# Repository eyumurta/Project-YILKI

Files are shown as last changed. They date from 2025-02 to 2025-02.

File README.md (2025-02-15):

This is the first Prototype of Open Plc Controller Board Yılkı.This project devoloped with Eagle
Project started 2024.
First Protype doesn't have built in Power,mcu circuits. This PT1 is only creating for testing input,output and Rs485 line.
I'm not a hardware engineer so project maybe have faulty designs.This Board using Stm32f0 Discovery board to handle inputs and outputs.
You can see inputs state by LED.But power calculations are wrong so I'm not soldered the Leds and their resistors.In theory boards outputs can drive relay but not tested. 

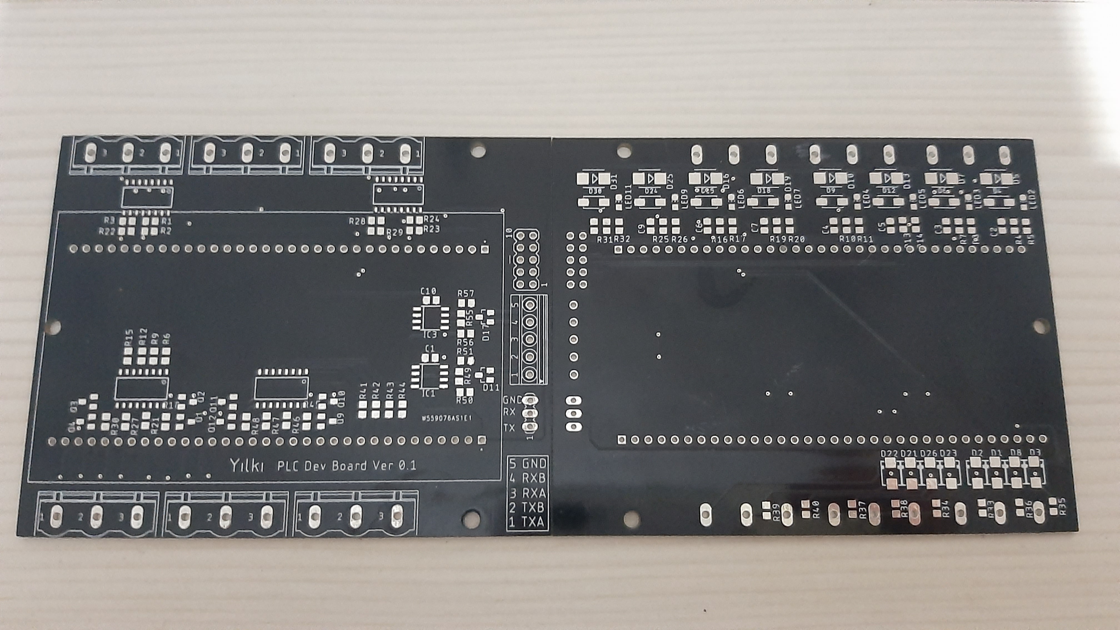
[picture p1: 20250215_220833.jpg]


Input Side:
Inputs Are Designed sink (0v Common).Protected by TVS diode and optocoupler.Added RC filter for ripples.

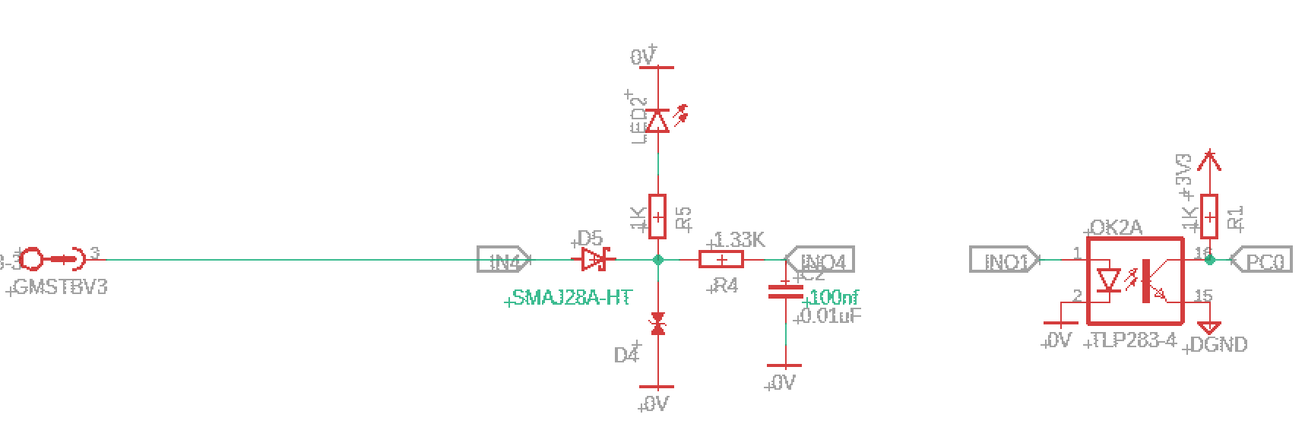
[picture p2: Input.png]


Output Side:
Outputs are Designed source(24V Common).Outputs Protected by Optocoupler and reverse diode for relay.

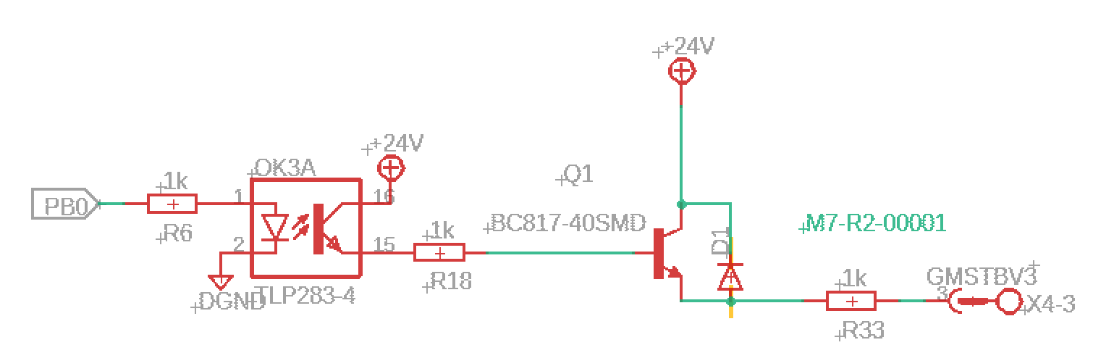
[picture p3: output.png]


Full Duplex RS-485:
This circuit is Full Duplex Rs-485 line

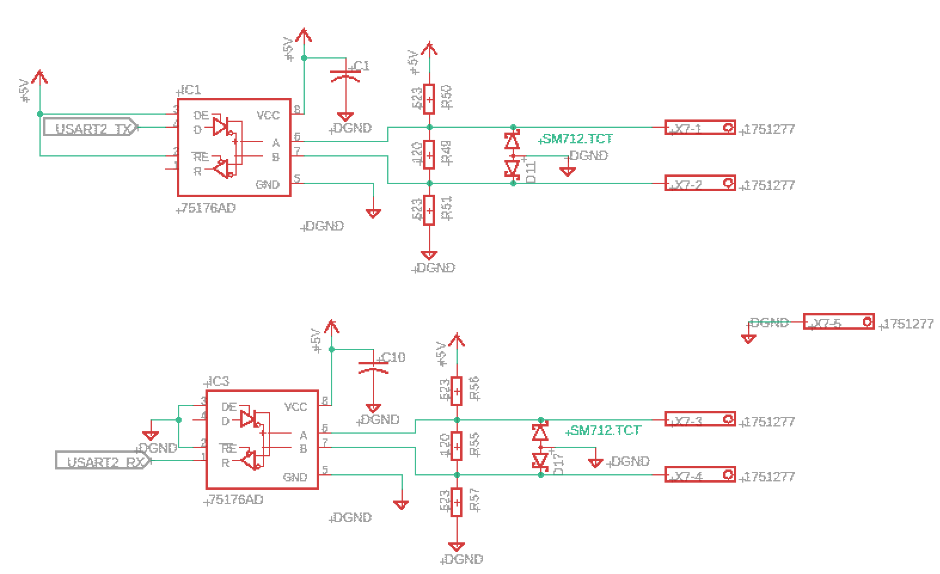
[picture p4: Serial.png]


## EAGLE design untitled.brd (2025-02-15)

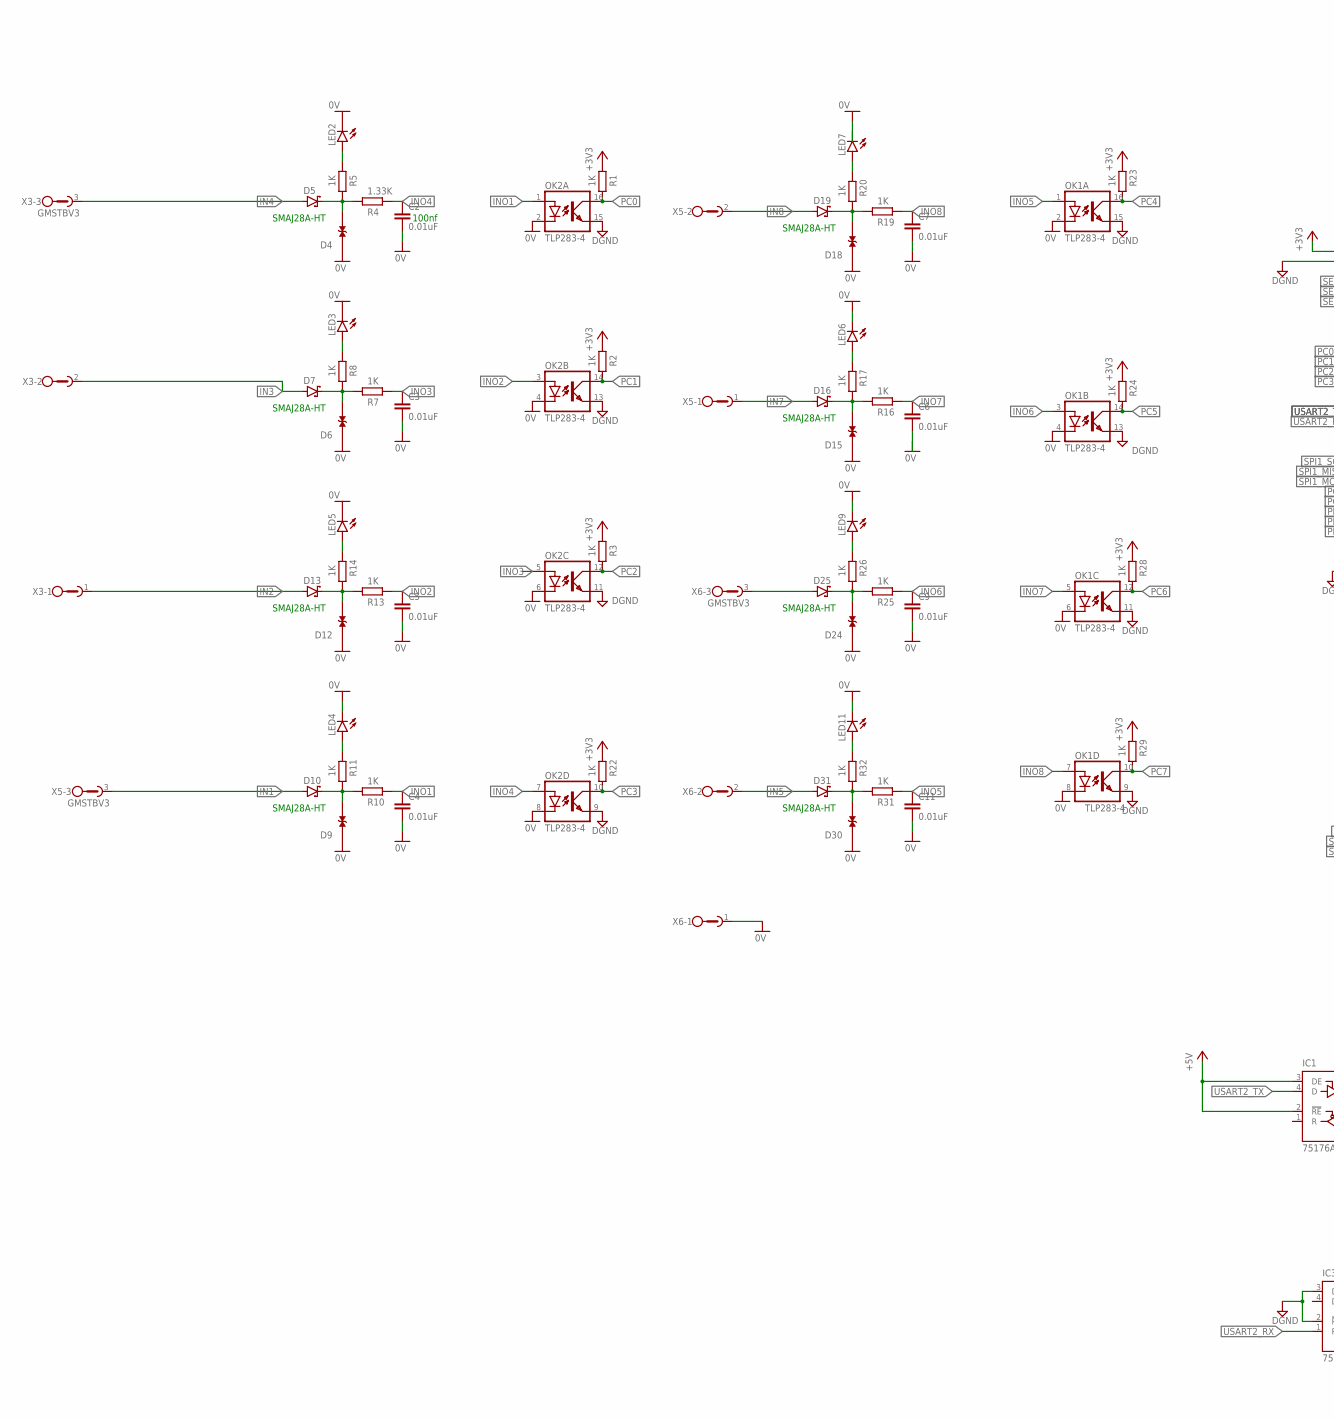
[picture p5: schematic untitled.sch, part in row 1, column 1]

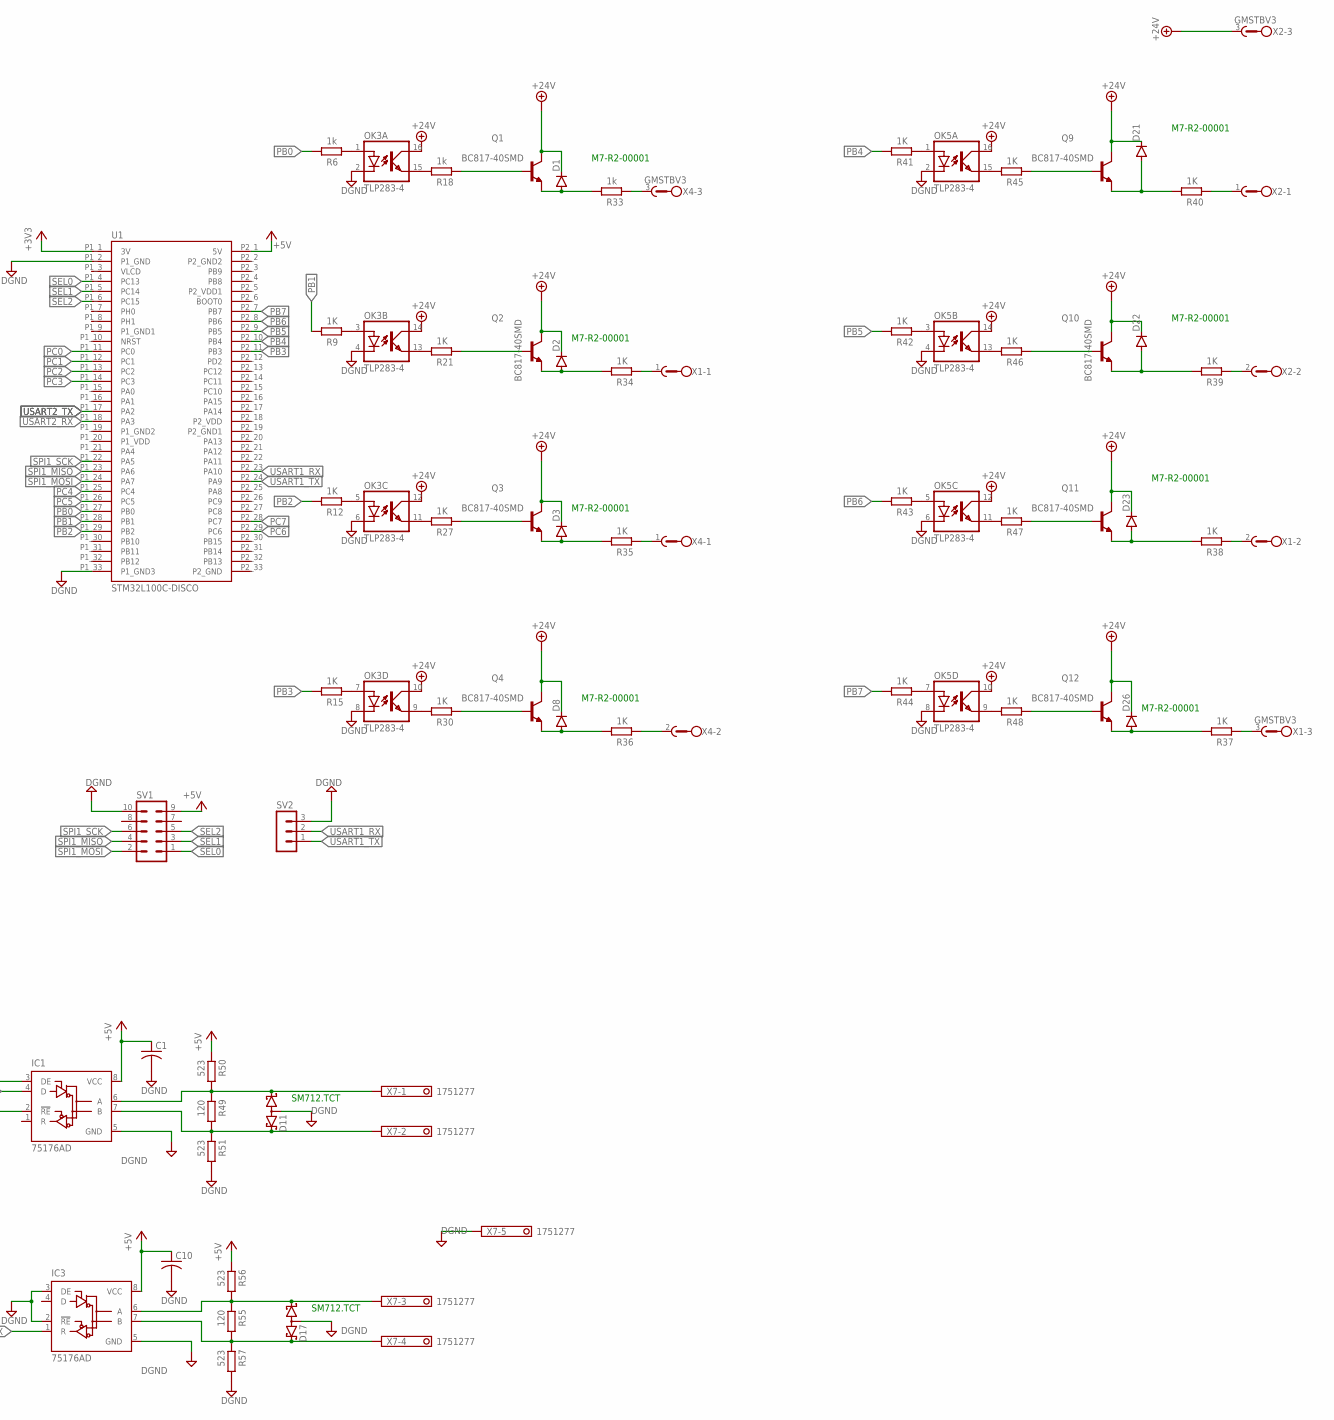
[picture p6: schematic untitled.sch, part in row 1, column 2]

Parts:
C1, C10: C-USC0805; C0805
C2, C3, C4, C5, C6, C7, C9, C11: 0.01uF; C0805
D1, D2, D3, D8, D21, D22, D23, D26: S1M; SMA
D4, D6, D9, D12, D15, D18, D24, D30: SMAJ28CA; DIOM4325X250N
D5, D7, D10, D13, D16, D19, D25, D31: SCHOTTKY-DIODESMD; SMB
D11, D17: BAS40-06; SOT23
IC1, IC3: 75176AD; D_R-PDSO-G8
LED2, LED3, LED4, LED5, LED6, LED7, LED9, LED11: LEDCHIP-LED0805; CHIP-LED0805
OK1, OK2, OK3, OK5: TLP283-4; MINI-FLAT-16
Q1, Q2, Q3, Q4, Q9, Q10, Q11, Q12: BC817-40SMD; SOT23-BEC
R1, R2, R3, R5, R7, R8, R9, R10, R11, R12, R13, R14, R15, R16, R17, R19, R20, R21, R22, R23, R24, R25, R26, R27, R28, R29, R30, R31, R32, R34, R35, R36, R37, R38, R39, R40, R41, R42, R43, R44, R45, R46, R47, R48: 1K; R0805
R4: 1.33K; R0805
R6, R18, R33: 1k; R0805
R49, R55: 120; R0805
R50, R51, R56, R57: 523; R0805
SV1: MA05-2
SV2: MA03-1
U1: STM32L100C-DISCO; DEV_STM32L100C-DISCO
X1, X2, X3, X4, X5, X6: GMSTBV3
X7: 1751277

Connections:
0V: C2.2, C3.2, C4.2, C5.2, C6.2, C7.2, C9.2, C11.2, D4.1, D6.1, D9.1, D12.1, D15.1, D18.1, D24.1, D30.1, LED2.C, LED3.C, LED4.C, LED5.C, LED6.C, LED7.C, LED9.C, LED11.C, OK1.2 (C), OK1.4 (C), OK1.6 (C), OK1.8 (C), OK2.2 (C), OK2.4 (C), OK2.6 (C), OK2.8 (C), X6.1
+3V3: R1.2, R2.2, R3.2, R22.2, R23.2, R24.2, R28.2, R29.2, U1.P1_1 (3V)
+5V: C1.1, C10.1, IC1.2 (!RE), IC1.3 (DE), IC1.8 (VCC), IC3.8 (VCC), R50.2, R56.2, SV1.9, U1.P2_1 (5V)
+24V: D1.C, D2.C, D3.C, D8.C, D21.C, D22.C, D23.C, D26.C, OK3.10 (COL), OK3.12 (COL), OK3.14 (COL), OK3.16 (COL), OK5.10 (COL), OK5.12 (COL), OK5.14 (COL), OK5.16 (COL), Q1.C, Q2.C, Q3.C, Q4.C, Q9.C, Q10.C, Q11.C, Q12.C, X2.3
DGND: C1.2, C10.2, D11.3 (AA), D17.3 (AA), IC1.5 (GND), IC3.2 (!RE), IC3.3 (DE), IC3.5 (GND), OK1.9 (EMIT), OK1.11 (EMIT), OK1.13 (EMIT), OK1.15 (EMIT), OK2.9 (EMIT), OK2.11 (EMIT), OK2.13 (EMIT), OK2.15 (EMIT), OK3.2 (C), OK3.4 (C), OK3.6 (C), OK3.8 (C), OK5.2 (C), OK5.4 (C), OK5.6 (C), OK5.8 (C), R51.1, R57.1, SV1.10, SV2.3, U1.P1_2 (P1_GND), U1.P1_33 (P1_GND3), X7.5
IN1: D10.A, X5.3
IN2: D13.A, X3.1
IN3: D7.A, X3.2
IN4: D5.A, X3.3
IN5: D31.A, X6.2
IN7: D16.A, X5.1
IN8: D19.A, X5.2
INO1: C4.1, OK2.1 (A), R10.2
INO2: C5.1, OK2.3 (A), R13.2
INO3: C3.1, OK2.5 (A), R7.2
INO4: C2.1, OK2.7 (A), R4.2
INO5: C11.1, OK1.1 (A), R31.2
INO6: C9.1, OK1.3 (A), R25.2
INO7: C6.1, OK1.5 (A), R16.2
INO8: C7.1, OK1.7 (A), R19.2
unnamed: LED2.A, R5.2
unnamed: LED3.A, R8.2
unnamed: LED4.A, R11.2
unnamed: LED5.A, R14.2
unnamed: LED6.A, R17.2
unnamed: LED7.A, R20.2
unnamed: LED9.A, R26.2
unnamed: LED11.A, R32.2
unnamed: D4.2, D5.C, R4.1, R5.1
unnamed: D6.2, D7.C, R7.1, R8.1
unnamed: D12.2, D13.C, R13.1, R14.1
unnamed: D9.2, D10.C, R10.1, R11.1
unnamed: D18.2, D19.C, R19.1, R20.1
unnamed: D15.2, D16.C, R16.1, R17.1
unnamed: D24.2, D25.C, R25.1, R26.1
unnamed: D30.2, D31.C, R31.1, R32.1
unnamed: OK3.1 (A), R6.2
unnamed: OK3.3 (A), R9.2
unnamed: OK3.5 (A), R12.2
unnamed: OK3.7 (A), R15.2
unnamed: OK3.15 (EMIT), R18.1
unnamed: OK3.13 (EMIT), R21.1
unnamed: OK3.11 (EMIT), R27.1
unnamed: OK3.9 (EMIT), R30.1
unnamed: Q4.B, R30.2
unnamed: Q3.B, R27.2
unnamed: Q2.B, R21.2
unnamed: Q1.B, R18.2
unnamed: R33.2, X4.3
unnamed: R34.2, X1.1
unnamed: R35.2, X4.1
unnamed: D25.A, X6.3
unnamed: OK5.1 (A), R41.2
unnamed: OK5.15 (EMIT), R45.1
unnamed: OK5.3 (A), R42.2
unnamed: OK5.13 (EMIT), R46.1
unnamed: OK5.5 (A), R43.2
unnamed: OK5.11 (EMIT), R47.1
unnamed: OK5.7 (A), R44.2
unnamed: OK5.9 (EMIT), R48.1
unnamed: D1.A, Q1.E, R33.1
unnamed: R36.2, X4.2
unnamed: D2.A, Q2.E, R34.1
unnamed: D3.A, Q3.E, R35.1
unnamed: D8.A, Q4.E, R36.1
unnamed: D26.A, Q12.E, R37.1
unnamed: D23.A, Q11.E, R38.1
unnamed: D22.A, Q10.E, R39.1
unnamed: Q12.B, R48.2
unnamed: Q11.B, R47.2
unnamed: Q10.B, R46.2
unnamed: Q9.B, R45.2
unnamed: R37.2, X1.3
unnamed: R38.2, X1.2
unnamed: R39.2, X2.2
unnamed: R40.2, X2.1
unnamed: D21.A, Q9.E, R40.1
unnamed: D11.1 (K1), IC1.6 (A), R49.2, R50.1, X7.1
unnamed: D11.2 (K2), IC1.7 (B), R49.1, R51.2, X7.2
unnamed: D17.1 (K1), IC3.6 (A), R55.2, R56.1, X7.3
unnamed: D17.2 (K2), IC3.7 (B), R55.1, R57.2, X7.4
P1_GND1: U1.P1_9 (P1_GND1)
P1_GND2: U1.P1_19 (P1_GND2)
P1_VDD: U1.P1_20 (P1_VDD)
P2_GND: U1.P2_33 (P2_GND)
P2_GND1: U1.P2_19 (P2_GND1)
P2_GND2: U1.P2_2 (P2_GND2)
P2_VDD: U1.P2_18 (P2_VDD)
P2_VDD1: U1.P2_5 (P2_VDD1)
PB0: R6.1, U1.P1_27 (PB0)
PB1: R9.1, U1.P1_28 (PB1)
PB2: R12.1, U1.P1_29 (PB2)
PB3: R15.1, U1.P2_11 (PB3)
PB4: R41.1, U1.P2_10 (PB4)
PB5: R42.1, U1.P2_9 (PB5)
PB6: R43.1, U1.P2_8 (PB6)
PB7: R44.1, U1.P2_7 (PB7)
PC0: OK2.16 (COL), R1.1, U1.P1_11 (PC0)
PC1: OK2.14 (COL), R2.1, U1.P1_12 (PC1)
PC2: OK2.12 (COL), R3.1, U1.P1_13 (PC2)
PC3: OK2.10 (COL), R22.1, U1.P1_14 (PC3)
PC4: OK1.16 (COL), R23.1, U1.P1_25 (PC4)
PC5: OK1.14 (COL), R24.1, U1.P1_26 (PC5)
PC6: OK1.12 (COL), R28.1, U1.P2_29 (PC6)
PC7: OK1.10 (COL), R29.1, U1.P2_28 (PC7)
SEL0: SV1.1, U1.P1_4 (PC13)
SEL1: SV1.3, U1.P1_5 (PC14)
SEL2: SV1.5, U1.P1_6 (PC15)
SPI1_MISO: SV1.4, U1.P1_23 (PA6)
SPI1_MOSI: SV1.2, U1.P1_24 (PA7)
SPI1_SCK: SV1.6, U1.P1_22 (PA5)
USART1_RX: SV2.2, U1.P2_23 (PA10)
USART1_TX: SV2.1, U1.P2_24 (PA9)
USART2_RX: IC3.1 (R), U1.P1_18 (PA3)
USART2_TX: IC1.4 (D), U1.P1_17 (PA2)
VLCD: U1.P1_3 (VLCD)

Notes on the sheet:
SMAJ28A-HT
M7-R2-00001
SM712.TCT
100nf

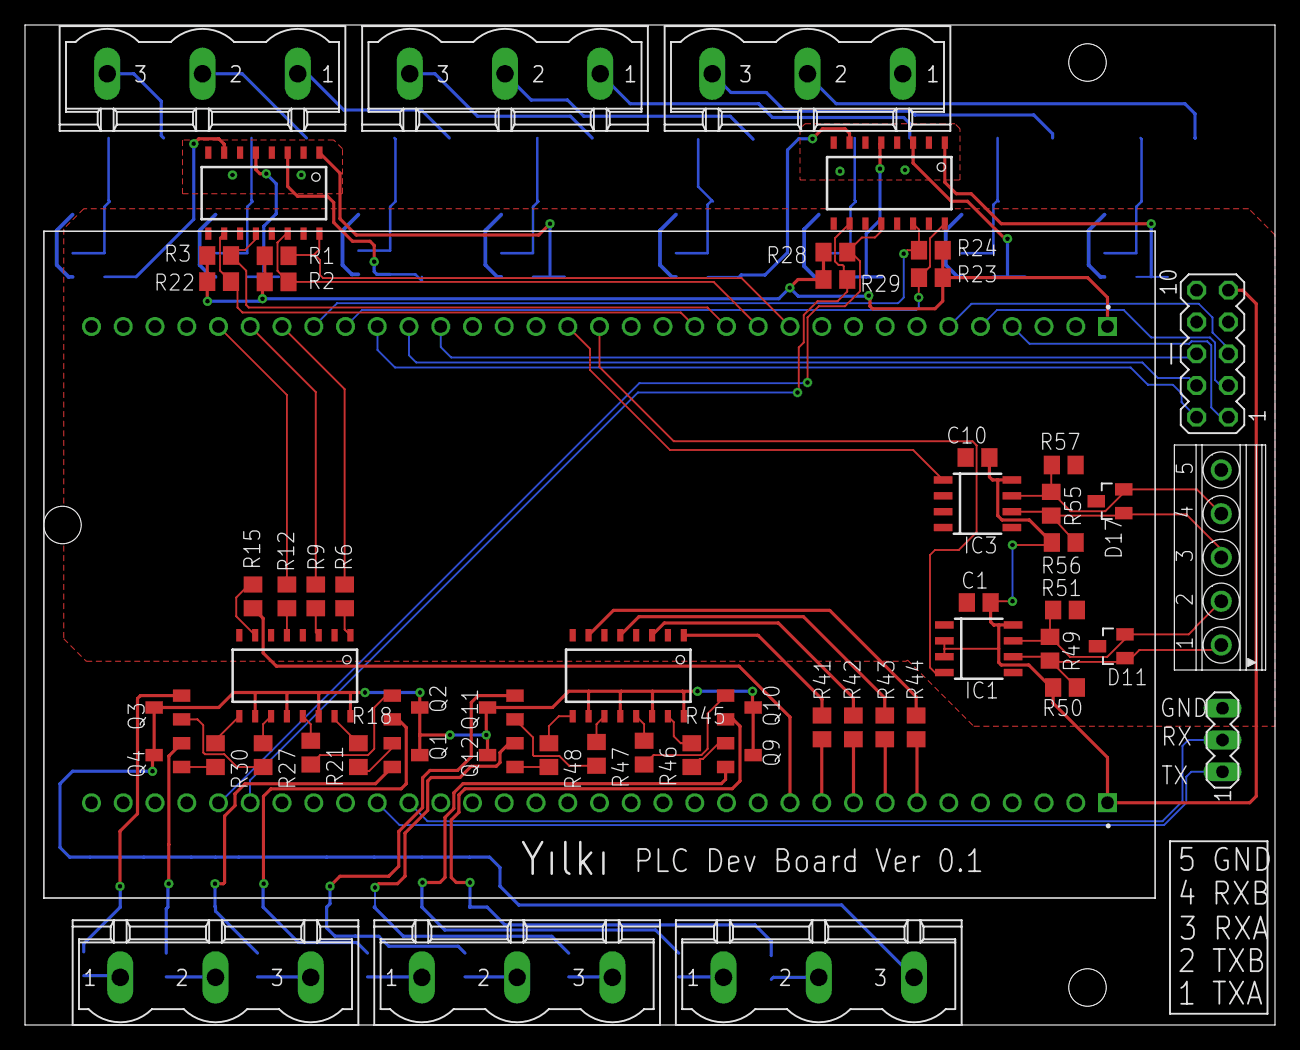
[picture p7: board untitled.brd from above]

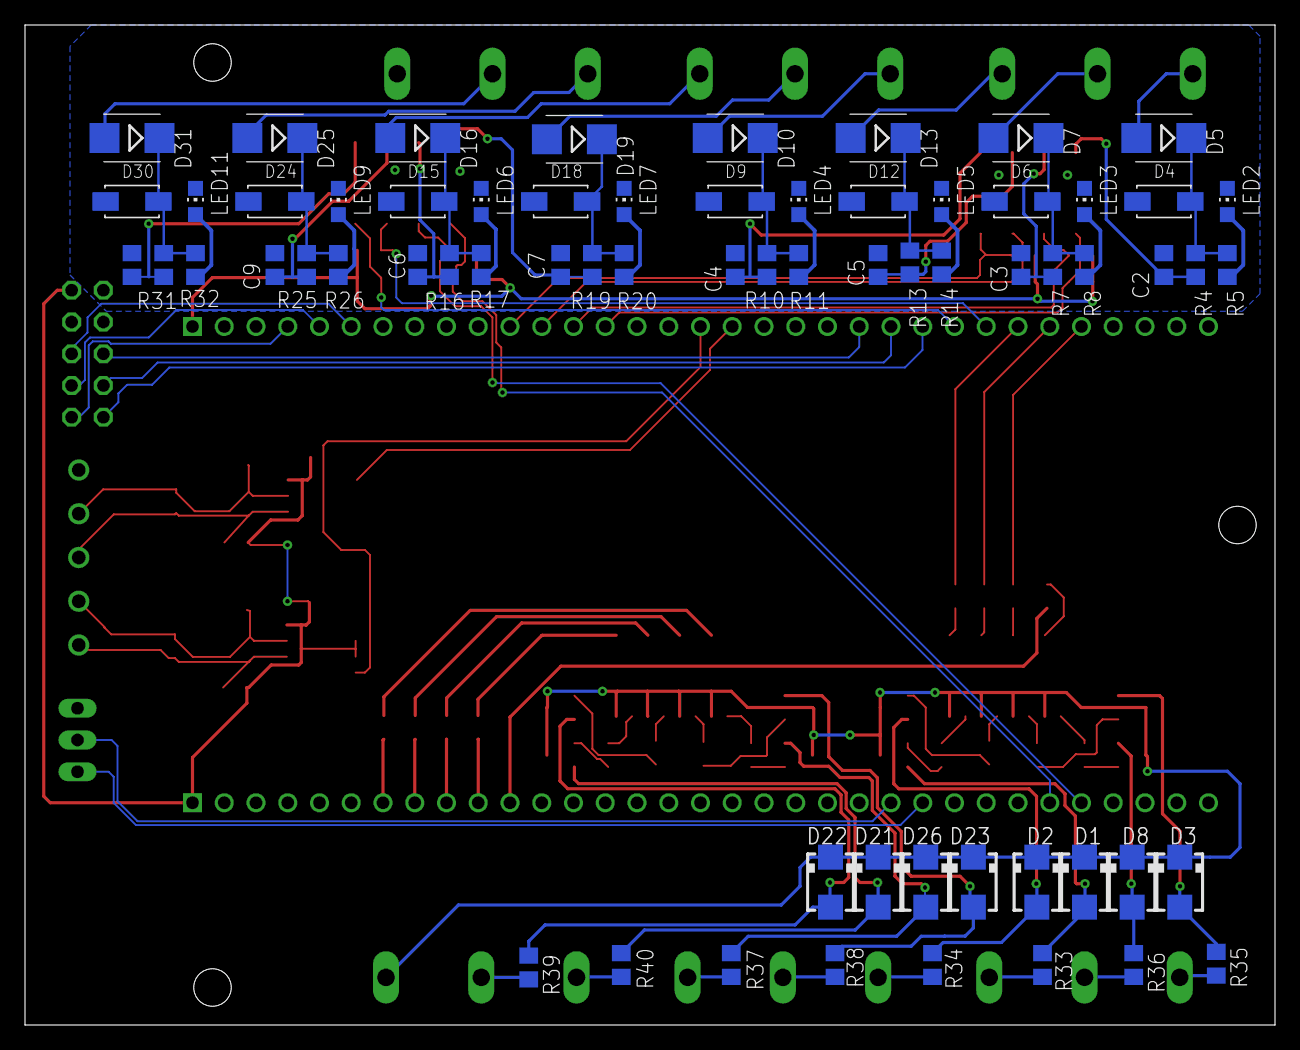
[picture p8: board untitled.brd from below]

Board: 2 copper layers, 100.0 x 80.0 mm, 122 parts (64 on the bottom side), 107 nets.
